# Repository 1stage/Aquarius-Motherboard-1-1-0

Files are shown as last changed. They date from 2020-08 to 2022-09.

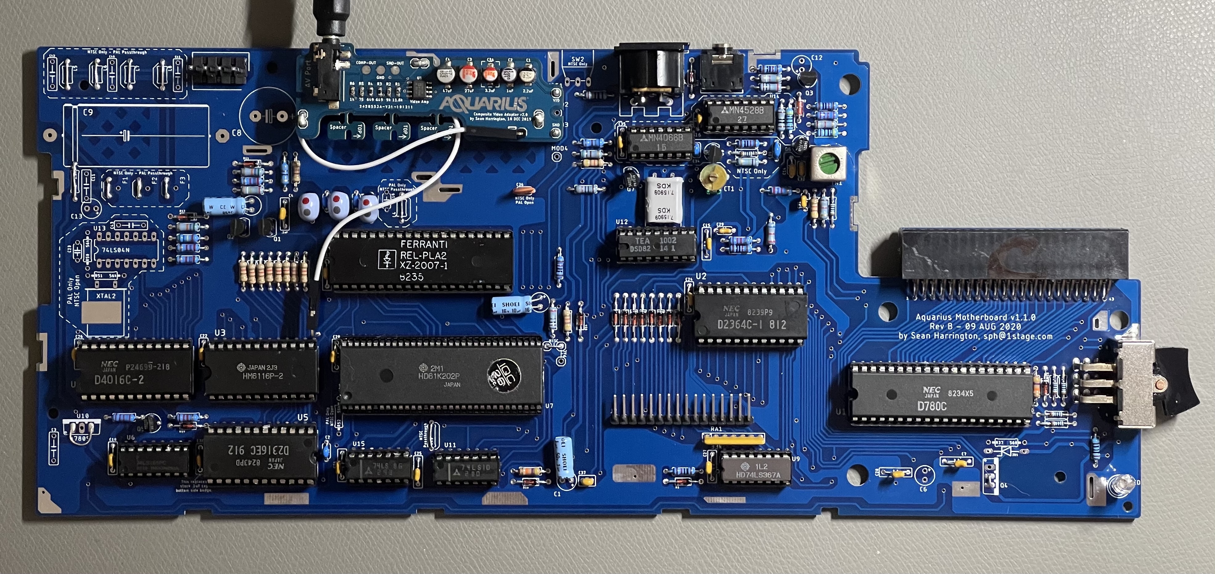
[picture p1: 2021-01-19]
docs/20210119_115113_IMG_6803.JPG

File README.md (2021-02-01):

# Aquarius Motherboard 1-1-0
Aquarius Motherboard 1-1-0 - Rev C

by Sean P. Harrington, sph@1stage.com, http://aquarius.1stage.com, Mack Wharton, aquarius@mack.je, http://aquarius.je
 
## Background
In general, the Aquarius hardware is fairly hardy. Few of the parts go bad, and the system just works, even when stored in harsh or unforgiving environments. Add to that the poor reception the computer had during its brief, 3-4 month sales window in 1983, and there is no REAL reason most people would be interested. But the Mattel Aquarius Computer was the first computer I ever owned. I learned first hand how to program in BASIC, and then how to hack together an audio cable to save those programs to my inexpensive Radio Shack cassette player. However I quickly grew out of it's limited functionality and moved on to a Commodore 64, and then an Apple Macintosh SE, and then Mac II, and then various Windows PCs. It wasn't until Summer of 2019 that I started getting back into retro computers, and it was the pang of guilt I felt in abandoning my first Aquarius that brought me back in.

## Purpose
The purpose of this project is to document and recreate the original Aquarius computer motherboard. This is a like-for-like replacement, and should fit in perfectly in place of the old motherboard. This baseline can be used by other enthusiasts (though we are few and far between) as a starting point for creating new modifications to the system, such as adding a composite video adapter (which I've done) to replace the stock RF modulator, or adding more modern components to "future proof" the system.

Additionally, there was a need to update and correct the "MEKO" schematic from 1986. It was drawn from the PAL board, and values for various components seemed to differ from what was commonly manufactured. From these new schematics, users are welcome to adapt and integrate their own ideas, OR to recreate the system in their eCAD program of choice.

## Caveats
* Some fixes to the stock board were made:
  * The .1uF capacitor that was bodged under U6 has been given a proper set of pads beside U6.
  * Silkscreens were added, with all components being identified. Unfortunately, due to the poor quality of original Radofin documents on the Internet, I had to take a stance and perform a re-number of components, particularly resistors and capacitors. In some cases, these won't match original numbers, but every effort was made to get them as close as possible.
  * Both the PAL-only and NTSC-only components are marked, but only the components for the version being built should be used.
  * As much as possible, original trace paths were recreated (particularly CPU to expansion port), but the traces have been reduced to a 20 mil width on most signals, with all GND and power paths increased to 32 mil width.
  * GND pins now have thermal pads to make soldering and desoldering easier.
* The libraries within the Eagle folder are a mess. I apologize. The board uses a combination of the standard Eagle libraries, some copied/modified versions of those, and some of my own items. I'll eventually try to consolidate them into a single library file. Again, apologies.
* This design was taken from the NTSC version of the Aquarius Motherboard, Radofin part number 5931-4229 A. The values for all components are derived from the NTSC version, and where practical, PAL component values are noted on the schematic. As such, the "part number" embossed on these designs uses 5931-4229 AC to differentiate.
* The schematic does it's best to identify differences between the NTSC and PAL versions, usually with dashed lines surrounding the differences.

## FAQs
* Will these boards be available for sale?
  * https://www.pcbway.com/project/shareproject/Aquarius_Computer_Motherboard_v1_1_0_Rev_C.html
* Can I manufacture and sell the boards myself?
  * Sure, but see the section below on why this is more for SERIOUS hackers than casual users.
* Can you build me a new Aquarius with this PCB?
  * No. I have way too many projects at this time. Also, cost of the components ($$) and my time testing and assembling ($$$) would make this MANY times more expensive than buying a used Aquarius off of eBay.
* Can I build my own, brand new Aquarius computer with this PCB?
  * Realistically, no. There are a handful of custom components (bespoke, we like to say) that ONLY exist in the Aquarius computer... the PLA1 and PLA2, some line filters, and a variable inductor... each of which is impractical to source new/NOS. You will HAVE to cannibalize an old Aquarius to get your new Aquarius to work, so given that, you should PROBABLY just use that old Aquarius instead. They're REMARKABLY robust, and the added time and cost of soldering and testing each component on your new board could just as easily be spent learning about your old computer.
* Okay, so then what's the point of this PCB?
  * For futher development to happen to expand the platform, it was necessary to do the work to document the original Aquarius motherboard. From there, people who are interested in adding new components will have a safer, better-documented source from which to start that development. Examples are an RGB or HDMI video interface, incorporated 32Kb of RAM on the motherboard, USB/SD support, etc.
* I don't use Eagle (too expensive), so will you be making this available in KiCAD or some other open-source/free PCB design tool?
  * No, but with the documentation that exists now, feel free to do so yourself. If everyone agrees that your new files work okay, we'll be happy to add them to this project.
* What's next?
  * See the HW Roadmap (below) for our vision.

## Aquarius Hardware Development Roadmap
(A more up-to-date version of this list is at https://aquarius.1stage.com/aquarius/hw-roadmap)

### Aquarius v1.0.0 : Baseline
* Aquarius v1.1.0 (Rev C): Aquarius 1 stock motherboard, like-for-like replacement, SANCTIONED FREE version. 
  * Aquarius v1.1.0.x : Users can fork at this level for their own purposes, UNSANCTIONED versions.
* Aquarius v1.2.0 : Aquarius 1 modernized motherboard, fits in Aquarius 1 case, unmodified port openings may be used differently, SANCTIONED PAID version.
  * Aquarius v1.2.1 : Integrated composite video ???
  * Aquarius v1.2.2 : Modern power supply ???
  * Aquarius v1.2.3 : Charmap, ROM, updates ???
* Aquarius v1.3.0 : Aquarius 1 motherboard, new layout, new case format, etc. ???
  * Aquarius v1.3.1 : New case design with mechanical keyboard, RGB output, proper serial, etc. ???

### Aquarius v2.0.0 : Baseline (FUTURE)
* Aquarius v2.1.0 : Aquarius 2 stock motherboard, like-for-like replacement, SANCTIONED FREE version.
  * Aquarius v2.1.0.x : Users can fork at this level for their own purposes, UNSANCTIONED versions.
  * Aquarius v2.1.1 : Aquarius 2 motherboard, updated with proper silk screen markings and ground planes, SANCTIONED PAID version.
  * Aquarius v2.1.2 : Aquarius 2 motherboard, updated with bodge fixes, modern component replacements, traces may be updated/optimized, SANCTIONED PAID version.
* Aquarius v2.2.0 : Aquarius 2 modernized motherboard, fits in Aquarius 2 case, unmodified port openings may be used differently, SANCTIONED PAID version.
  * Aquarius v2.2.1 : Charmap, ROM, etc updates ???
* Aquarius v2.3.0 : Aquarius 2 motherboard, new layout, new case format, etc. ???

### Aquarius v3.0.0 : Baseline (FUTURE)
New OPEN computer, modern, programmable system (new video system, RAM system, sound, etc.)
* Aquarius v3.1.0 : Aquarius 3 motherboard, SANCTIONED FREE version

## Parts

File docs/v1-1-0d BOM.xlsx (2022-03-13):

Part | NTSC Value | PAL Value | Device | Package
C1 | 1uF@50 | 10uF@16 | CPOL-USE2.5-6 | E2,5-6
C2 | 10pF | 10pF | C-US050-024X044 | C050-024X044
C3 | .22uF | .22uF | C-US050-025X090 | C050-025X090
C4 | .1uF | .1uF | C-US050-025X090 | C050-025X090
C5 | 2.2uF@50v | 2.2uF@50v | CPOL-USE2.5-6 | E2,5-6
C6 | 47uF@10v | 47uF@10v | CPOL-USE2.5-6 | E2,5-6
C7 | .1uF@25v | .1uF@25v | C-US050-025X090 | C050-025X090
C8 | 1000uF@25v | 1000uF@25v | CPOL-USE7.5-16 | E7,5-16
C9 | 10000uF@16v | 10000uF@16v | CPOL-USE45-18AXIAL | E45-18
C10 | .1uF | .1uF | C-US050-025X090 | C050-025X090
C11 | .1uF | .1uF | C-US050-025X090 | C050-025X090
C12 | 10uF@16v | 10uF@16v | CPOL-USE2.5-6 | E2,5-6
C13 | 10uF@25v | 10uF@25v | CPOL-USE2.5-6 | E2,5-6
C14 | .022uF | .022uF | C-US050-024X044 | C050-024X044
C15 | .1uF | .1uF | C-US050-025X090 | C050-025X090
C16 | open | 82pF | C-US050-024X044 | C050-024X044
C17 | .1uF | .1uF | C-US050-025X090 | C050-025X090
C18 | 82pF | 82pF | C-US050-024X044 | C050-024X044
C19 | 82pF | 82pF | C-US050-024X044 | C050-024X044
C20 | .1uF | .1uF | C-US050-025X090 | C050-025X090
C21 | .1uF | .1uF | C-US050-025X090 | C050-025X090
C22 | .1uF | .1uF | C-US050-025X085 | C050-025X085
C23 | open | 10pF | C-US050-024X044 | C050-024X044
C24 | .1uF | .1uF | C-US050-025X090 | C050-025X090
C25 | .1uF | .1uF | C-US050-025X090 | C050-025X090
C26 | .1uF | .1uF | C-US050-025X085 | C050-025X085
C27 | .1uF | .1uF | C-US050-025X090 | C050-025X090
C28 | .1uF | .1uF | C-US050-025X090 | C050-025X090
C29 | 150pF | 150pF | C-US050-024X044 | C050-024X044
C30 | 10uF@16v | 10uF@16v | CPOL-USE2.5-6 | E2,5-6
C31 | .1uF | .1uF | C-US050-024X044 | C050-024X044
C32 | 100pF | 100pF | C-US025-024X044 | C025-024X044
C33 | 680pF | open | C-US050-024X044 | C050-024X044
C34 | 2pF | open | C-US025-024X044 | C025-024X044
C35 | .1uF | open | C-US050-025X090 | C050-025X090
C36 | .01uF | .01uF | C-US050-024X044 | C050-024X044
C37 | .001uF | open | C-US025-030X050 | C025-030X050
C38 | 100pF | 100pF | C-US050-025X085 | C050-025X085
C39 | 56pF | open | C-US050-024X044 | C050-024X044
C40 | .02uF | .02uF | C-US050-025X090 | C050-025X090
C41 | .02uF | .02uF | C-US050-025X090 | C050-025X090
C42 | .02uF | .02uF | C-US050-025X090 | C050-025X090
C43 | open | 100nF | C-US050-025X090 | C050-025X090
C44 | open | 22pF | C-US050-024X044 | C050-024X044
CT1 | C-TRIMM808 | C-TRIMM808 | CTRIM808-BC | Trimmcapacitor
D1 | 1N4148 | 1N4148 | 1N4148 | DO35-10
D2 | 1N4148H | 1N4148H | 1N4148-12 | DO35-12
D3 | 1N4148H | 1N4148H | 1N4148-12 | DO35-12
D4 | 1N4148H | 1N4148H | 1N4148-12 | DO35-12
D5 | 1N4148H | 1N4148H | 1N4148-12 | DO35-12
D6 | 1N4148H | 1N4148H | 1N4148-12 | DO35-12
D7 | 1N4148H | 1N4148H | 1N4148-12 | DO35-12
D8 | 1N4148H | 1N4148H | 1N4148-12 | DO35-12
D9 | 1N4148H | 1N4148H | 1N4148-12 | DO35-12
D10 | 1N4148 | 1N4148 | 1N4148 | DO35-10
D11 | 1N4148 | 1N4148 | 1N4148 | DO35-10
D12 | 1N4148 | 1N4148 | 1N4148 | DO35-10
D13 | 1N4148 | 1N4148 | 1N4148 | DO35-10
D14 | 1N4148 | 1N4148 | 1N4148 | DO35-10
D15 | 1N4148 | 1N4148 | 1N4148 | DO35-10
D16 | 1N4148 | 1N4148 | 1N4148 | DO35-10
F1 | LCL | LCL | LCL | FILTER
F2 | LCL | LCL | LCL | FILTER
F3 | LCL | LCL | LCL | FILTER
J1 | CR22A-44D-2.54DSA(70)CR22A-44D-2.54DSA(70)CR22A-44D-2.54DSA(70) | CR22A-44D-2.54DSA(70)CR22A-44D-2.54DSA(70)CR22A-44D-2.54DSA(70)
J2 | PINHD-1X17 | PINHD-1X17 | 1X17 | PINHEADER
J3 | 26-60-4040 | 26-60-4040 | 26-60-4040 | SHDR4W155P0X396_1X4_
J4 | AUDIO_JACK_3.5MM_PTH | AUDIO_JACK_3.5MM_PTH | AUDIO_JACK_3.5MM_PTH | AUDIO-JACK
J5 | DIN5 | DIN5 | DIN5 | DIN5-RA-PTH
JP1 | PINHD-1X1 | PINHD-1X1 | 1X01 | PINHEADER
JP2 | PINHD-1X1 | PINHD-1X1 | 1X01 | PINHEADER
JP3 | PINHD-1X1 | PINHD-1X1 | 1X01 | PINHEADER
JP4 | PINHD-1X4 | PINHD-1X4 | 1X04 | PINHEADER
JP5 | PINHD-1X1 | PINHD-1X1 | 1X01 | PINHEADER
JP6 | PINHD-1X1 | PINHD-1X1 | 1X01 | PINHEADER
L-V1 | 10uH@4.43MHz | 10uH@4.43MHz | 10MM-VAR-IND | CL2054-136CB
L1 | L-USTFI0305 | L-USTFI0305 | TFI0305 | INDUCTOR,Americansymbol
L2 | L-USTFI0305 | L-USTFI0305 | TFI0305 | INDUCTOR,Americansymbol
L3 | L-USTFI0305 | L-USTFI0305 | TFI0305 | INDUCTOR,Americansymbol
L4 | L-USTFI0305 | L-USTFI0305 | TFI0305 | INDUCTOR,Americansymbol
L5 | L-USTFI0305 | L-USTFI0305 | TFI0305 | INDUCTOR,Americansymbol
L6 | L-USTFI0305 | L-USTFI0305 | TFI0305 | INDUCTOR,Americansymbol
L7 | L-USTFI0305 | L-USTFI0305 | TFI0305 | INDUCTOR,Americansymbol
L8 | L-USTFI0305 | L-USTFI0305 | TFI0305 | INDUCTOR,Americansymbol
LED1 | LED5MM | LED5MM | LED5MM | LED
MOD1 | PINHD-1X1 | PINHD-1X1 | 1X01 | PINHEADER
MOD2 | PINHD-1X1 | PINHD-1X1 | 1X01 | PINHEADER
MOD3 | PINHD-1X1 | PINHD-1X1 | 1X01 | PINHEADER
MOD4 | PINHD-1X1 | PINHD-1X1 | 1X01 | PINHEADER
Q1 | NPN-TO90 | NPN-TO90 | TO92-E1 | NPNTransistror
Q2 | NPN-TO90 | NPN-TO90 | TO92-E1 | NPNTransistror
Q3 | PNP-TO90 | PNP-TO90 | TO92-E1 | PNPTransistror
Q4 | NPN-TO220V | NPN-TO220V | TO220V | NPNTransistror
Q5 | NPN-TO90 | NPN-TO90 | TO92-E1 | NPNTransistror
Q6 | PNP-TO90 | PNP-TO90 | TO92-E1 | PNPTransistror
Q7 | NPN-TO90 | NPN-TO90 | TO92-E1 | NPNTransistror
Q8 | NPN-TO90 | NPN-TO90 | TO92-E1 | NPNTransistror
R1 | 1k | 1k | R-US_0207/10 | 0207/10
R2 | 1k | 1k | R-US_0207/10 | 0207/10
R3 | 1k | 1k | R-US_0207/10 | 0207/10
R4 | 1k | 1k | R-US_0207/10 | 0207/10
R5 | 10k | 10k | R-US_0207/10 | 0207/10
R6 | 820 | 820 | R-US_0207/10 | 0207/10
R7 | 820 | 820 | R-US_0207/10 | 0207/10
R8 | 820 | 820 | R-US_0207/10 | 0207/10
R9 | 820 | 820 | R-US_0207/10 | 0207/10
R10 | 820 | 820 | R-US_0207/10 | 0207/10
R11 | 820 | 820 | R-US_0207/10 | 0207/10
R12 | 820 | 820 | R-US_0207/10 | 0207/10
R13 | 820 | 820 | R-US_0207/10 | 0207/10
R14 | 2.2k | 680 | R-US_0207/10 | 0207/10
R15 | 1.2k | 2.2k | R-US_0207/10 | 0207/10
R16 | 2.7k | 2.7k | R-US_0207/10 | 0207/10
R17 | 56k | 56k | R-US_0207/10 | 0207/10
R18 | 2.7k | 2.7k | R-US_0207/10 | 0207/10
R19 | 2.7k | 2.7k | R-US_0207/10 | 0207/10
R20 | 390 | 390 | R-US_0207/10 | 0207/10
R21 | 560k | 560k | R-US_0207/10 | 0207/10
R22 | 56k | 56k | R-US_0207/10 | 0207/10
R23 | 100 | 100 | R-US_0207/10 | 0207/10
R24 | 10k | 10k | R-US_0207/10 | 0207/10
R25 | 4.7k | 2.7k | R-US_0207/10 | 0207/10
R26 | 10k | 10k | R-US_0207/10 | 0207/10
R27 | 10k | 10k | R-US_0207/10 | 0207/10
R28 | 2.2k | 2.2k | R-US_0207/10 | 0207/10
R29 | 100 | 100 | R-US_0207/10 | 0207/10
R30 | 10k | 10k | R-US_0207/10 | 0207/10
R31 | 3.9k | 3.9k | R-US_0207/10 | 0207/10
R32 | 820 | 820 | R-US_0207/10 | 0207/10
R33 | 1.2k | 1.2k | R-US_0207/10 | 0207/10
R34 | 6.8k | 6.8k | R-US_0207/10 | 0207/10
R35 | 2.7k | 2.7k | R-US_0207/10 | 0207/10
R36 | 1.8k | 1.8k | R-US_0207/10 | 0207/10
R37 | 560 | 560 | R-US_0207/10 | 0207/10
R38 | 820 | 820 | R-US_0207/10 | 0207/10
R39 | 82 | 82 | R-US_0207/10 | 0207/10
R40 | 180 | 180 | R-US_0207/10 | 0207/10
R41 | 680 | 680 | R-US_0207/10 | 0207/10
R42 | 510 | 510 | R-US_0207/10 | 0207/10
R43 | 4.7k | 4.7k | R-US_0207/10 | 0207/10
R44 | 470 | 470 | R-US_0207/10 | 0207/10
R45 | 47k | 47k | R-US_0207/10 | 0207/10
R46 | 510 | 510 | R-US_0207/10 | 0207/10
R47 | 4.7k | 4.7k | R-US_0207/10 | 0207/10
R48 | 1.8k | 1.8k | R-US_0207/10 | 0207/10
R49 | bridge | 220 | R-US_0207/10 | 0207/10
R50 | open | 1.5k | R-US_0207/10 | 0207/10
R51 | open | 1.5k | R-US_0207/10 | 0207/10
R52 | open | 100 | R-US_0207/10 | 0207/10
R53 | 1k | 1k | R-US_0207/10 | 0207/10
R54 | 1.8k | 1.8k | R-US_0207/10 | 0207/10
R55 | 47k | open | R-US_0207/10 | 0207/10
R56 | 100k | open | R-US_0207/10 | 0207/10
R57 | 1k | open | R-US_0207/10 | 0207/10
R58 | 10k | open | R-US_0207/10 | 0207/10
R59 | 180 | open | R-US_0207/10 | 0207/10
R60 | 470 | open | R-US_0207/10 | 0207/10
RA1 | 33k | 33k | RN06 | RN-7
SW1 | 3PDT-AQ-SWITCH | 3PDT-AQ-SWITCH | 3PDT-AQ-SWITCH | 3PDT-AQ-SWITCH
SW2 | 9077-1 | 9077-1 | 9077-1 | 9077-1
U1 | Z80CPU | Z80CPU | DIL40 | Z80FAMILYDEVICE
U2 | DIL24-6 | DIL24-6 | DIL24-6 | DualInLine
U3 | 6116P | 6116P | DIL24-6 | MEMORY
U4 | 6116P | 6116P | DIL24-6 | MEMORY
U5 | DIL24-6 | DIL24-6 | DIL24-6 | DualInLine
U6 | 74LS165N | 74LS165N | 74LS165N | DIL16
U7 | HD61K202P-PLA1 | HD61K202P-PLA1 | HD61K202P-PLA1 | HD61K202P-PLA1
U8 | DIL40 | DIL40 | DIL40 | DualInLine
U9 | 74367N | 74367N | 74367N | DIL16
U10 | 7805 | 7805 | 7805TV | TO220V
U11 | 74LS10N | 74LS10N | 74LS10N | DIL14
U12 | DIL18 | DIL18 | DIL18 | DualInLine/Socket
U13 | 74LS04N | 74LS04N | 74LS04N | DIL14
U14 | 4528N | 4528N | 4528N | DIL16
U15 | 74LS86N | 74LS86N | 74LS86N | DIL14
U16 | 744066N | 744066N | 744066N | DIL14
XTAL1 | 7.15909MhZ | 8.867239MhZ | Q | CRYSTAL
XTAL2 | open | 7.15909Mhz | Q | CRYSTAL
ZD1 | ZENER-DIODEZD-10 | ZENER-DIODEZD-10 | ZDIO-10 | Z-Diode
ZD2 | ZENER-DIODEZD-7.5 | ZENER-DIODEZD-7.5 | ZDIO-7.5 | Z-Diode

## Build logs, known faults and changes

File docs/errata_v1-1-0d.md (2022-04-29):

# Errata - Rev D Boards
Updated 30 APR 2022, by Sean Harrington<br/>

## Abstract
Erratas to Rev D board.

## New
* None

## Feedback Needed
* None

## Resolved
* Fixed missing pad on BACK upper power switch mount.
* Added back pads between lower switch contacts.
* Added auxiliary power connector (+5v & GND) above PLA2 for Comp/HDMI solutions.

## Delayed / Out of Scope
* ROM & CHROM 24 to 28 pin change - Deferred. It's impractical to add on-board support for both 24 pin (stock) and 28 pin (modern replacement) headers. 19 JAN 2021, SPH.

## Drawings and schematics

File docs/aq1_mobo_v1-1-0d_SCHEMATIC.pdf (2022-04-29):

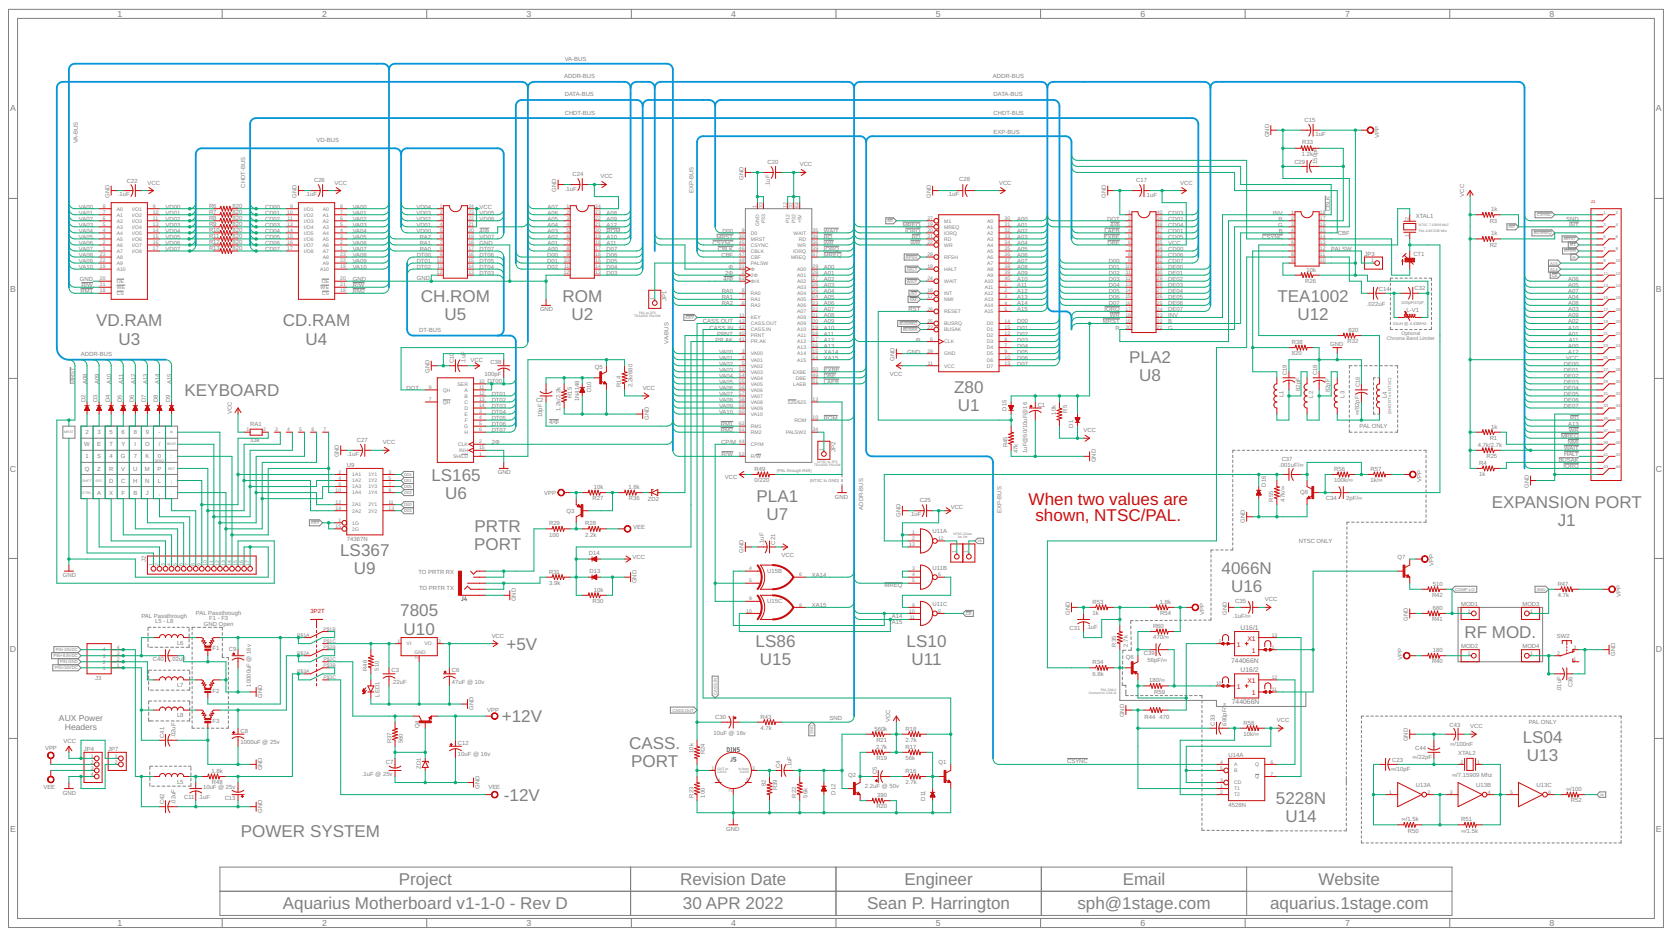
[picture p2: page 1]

Optional Chroma Band Limiter

(NTSC to GND) NTSC to JP3 TEA1002 PALSW

EXP-BUS
When two values are
shown, NTSC/PAL.

GND Open PAL Passthrough

PAL ONLY Connect to U16-11

CASS OUT to CASS

Project | Revision Date | Engineer | Email | Website

Aquarius Motherboard v1-1-0 - Rev D | 30 APR 2022 | Sean P. Harrington | sph@1stage.com | aquarius.1stage.com

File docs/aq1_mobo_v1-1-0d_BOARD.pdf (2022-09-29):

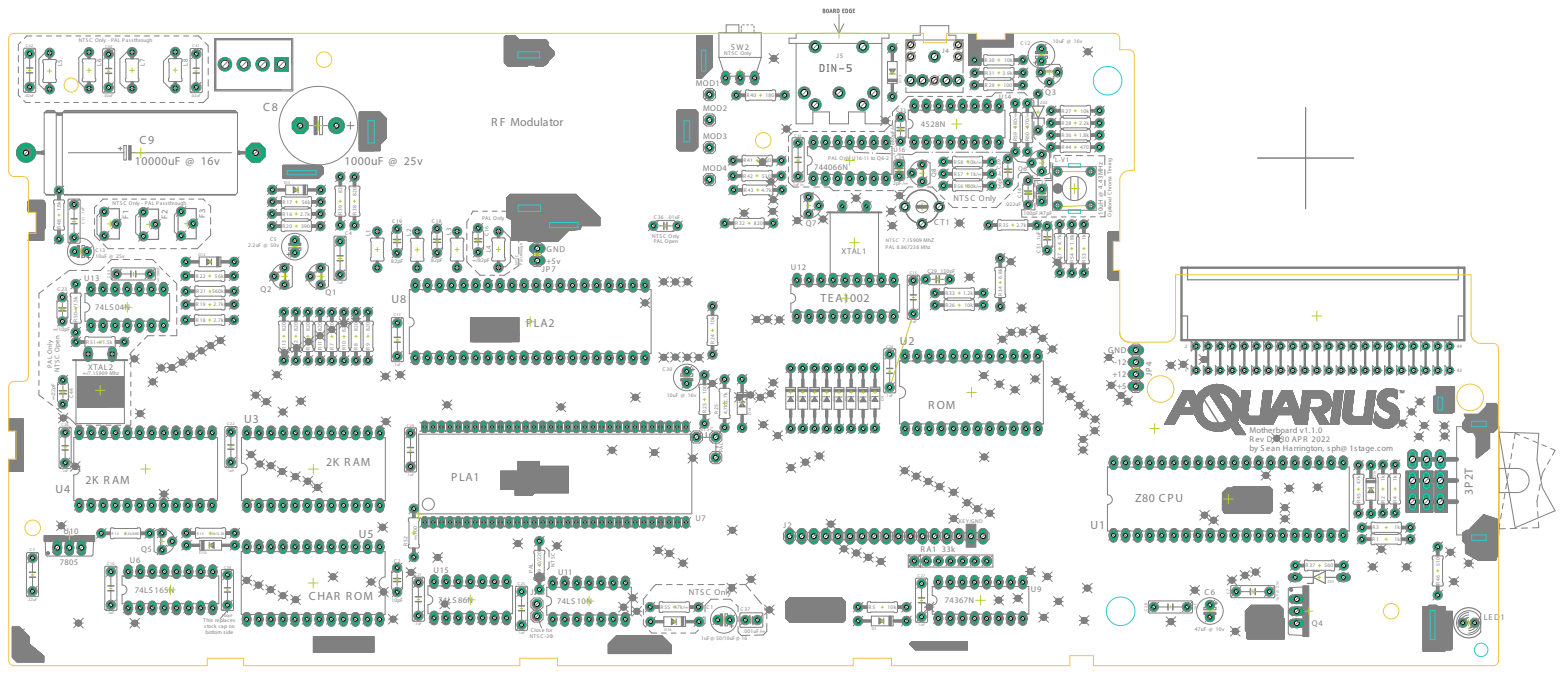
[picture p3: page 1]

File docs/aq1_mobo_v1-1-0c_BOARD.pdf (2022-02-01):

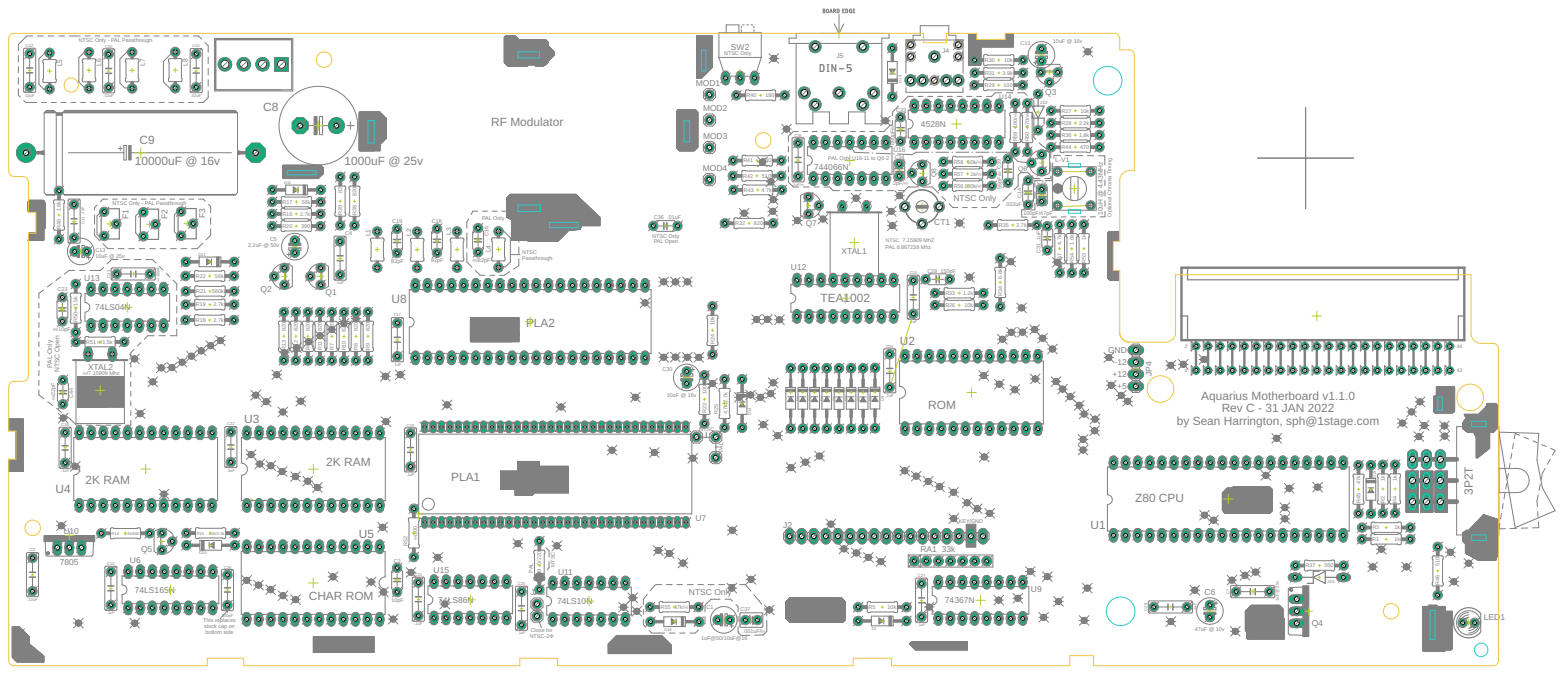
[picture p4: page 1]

NTSC Only - PAL Passthrough

PAL Only NTSC Only - PAL Passthrough

NTSC Only PAL Open

PAL Only NTSC Open

by Sean Harrington, sph@1stage.com

PAL Close for NTSC-2Φ

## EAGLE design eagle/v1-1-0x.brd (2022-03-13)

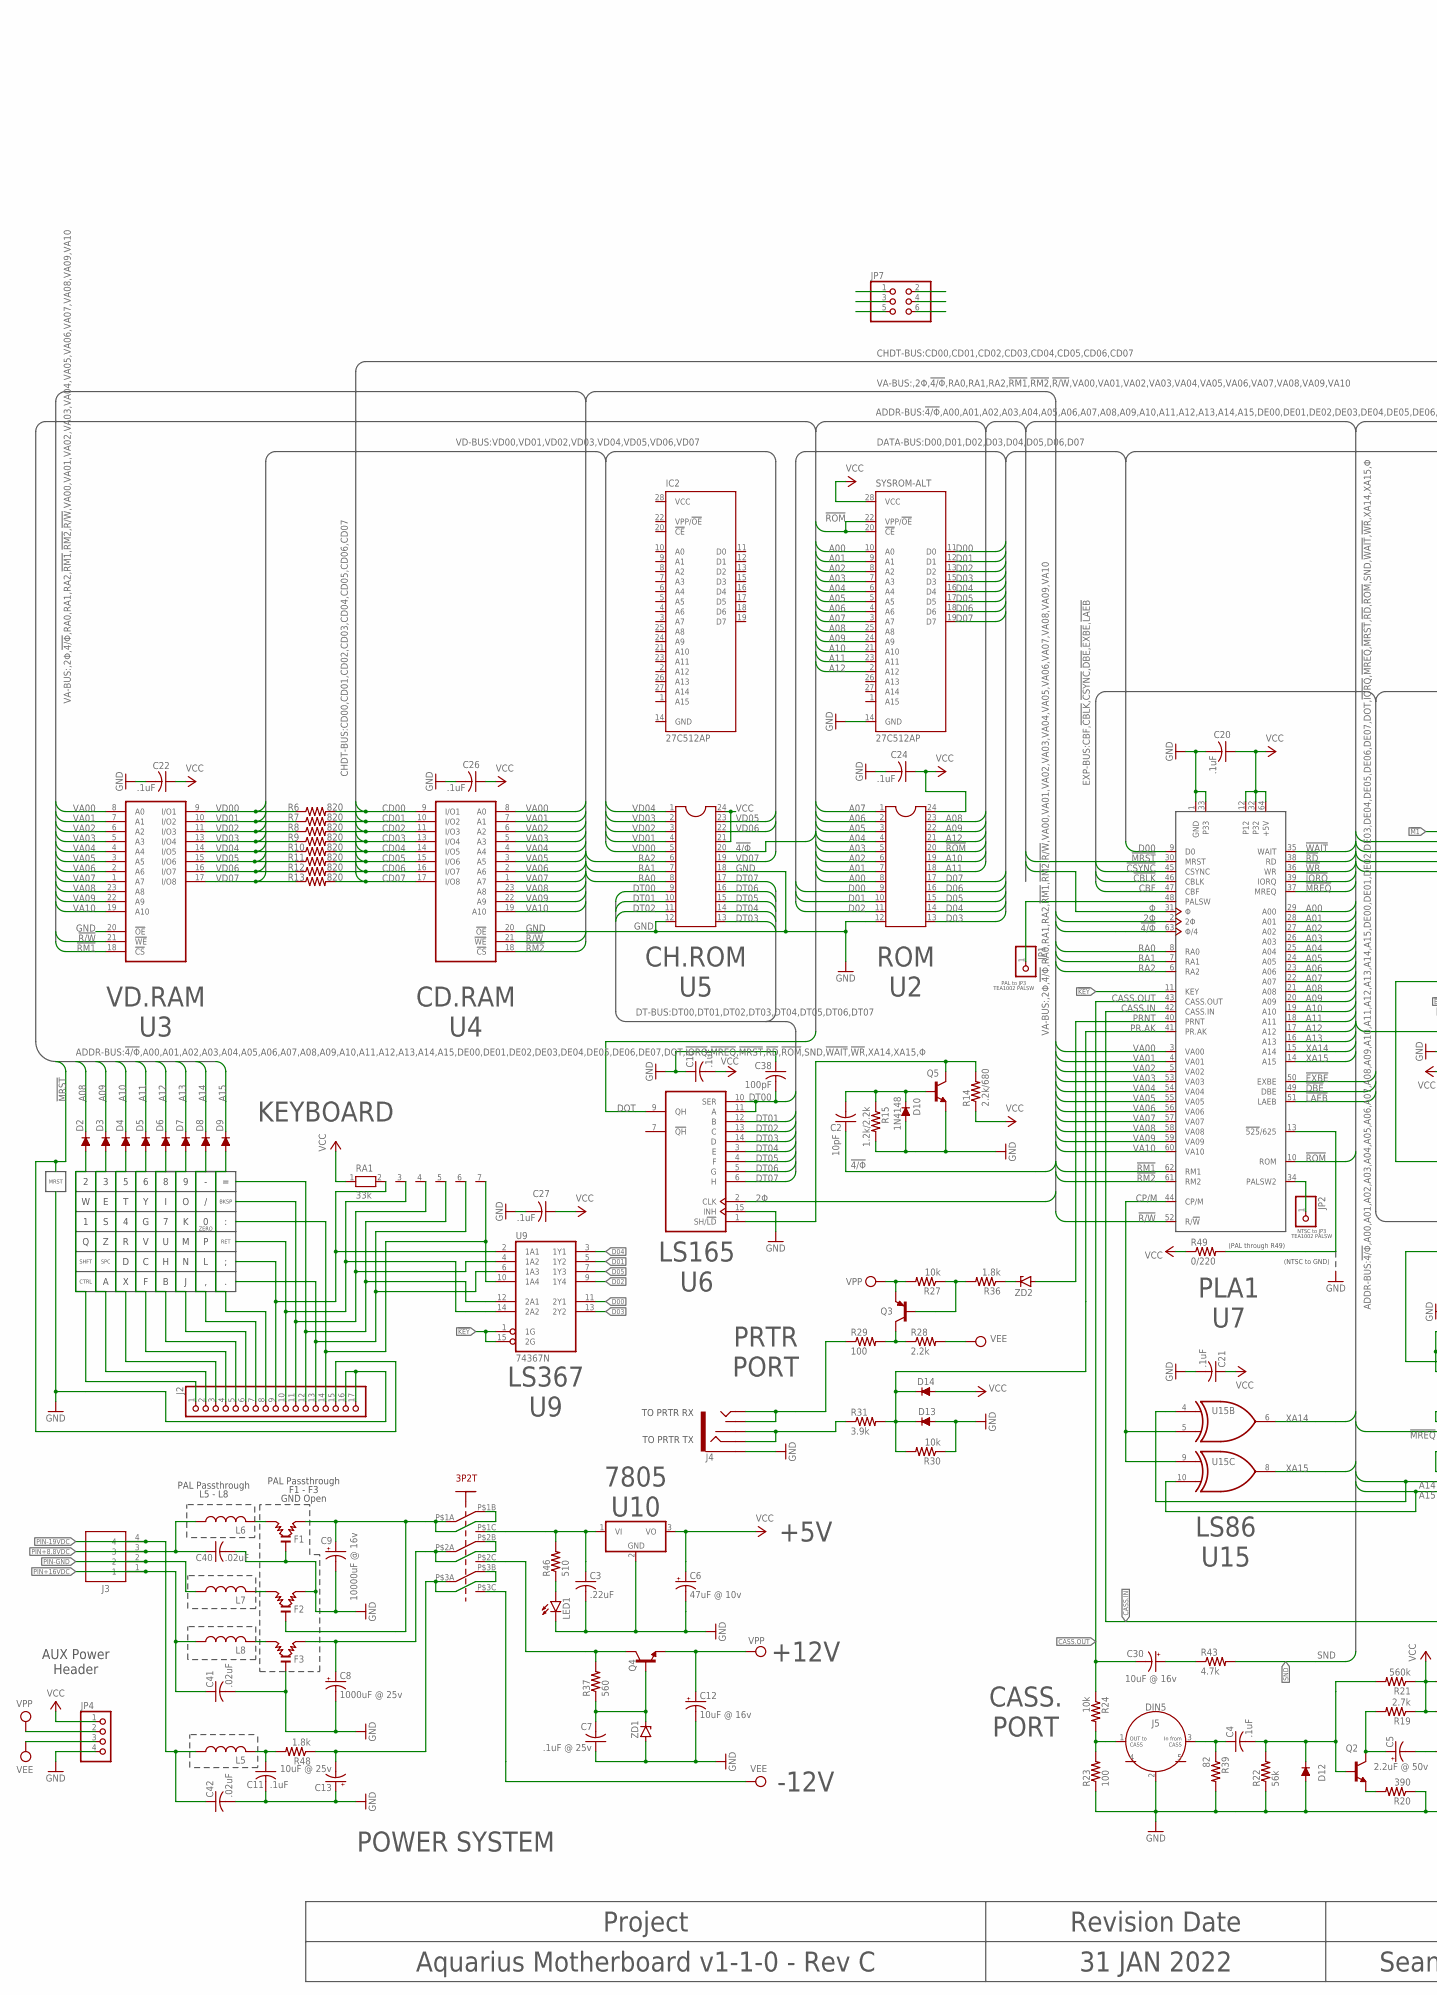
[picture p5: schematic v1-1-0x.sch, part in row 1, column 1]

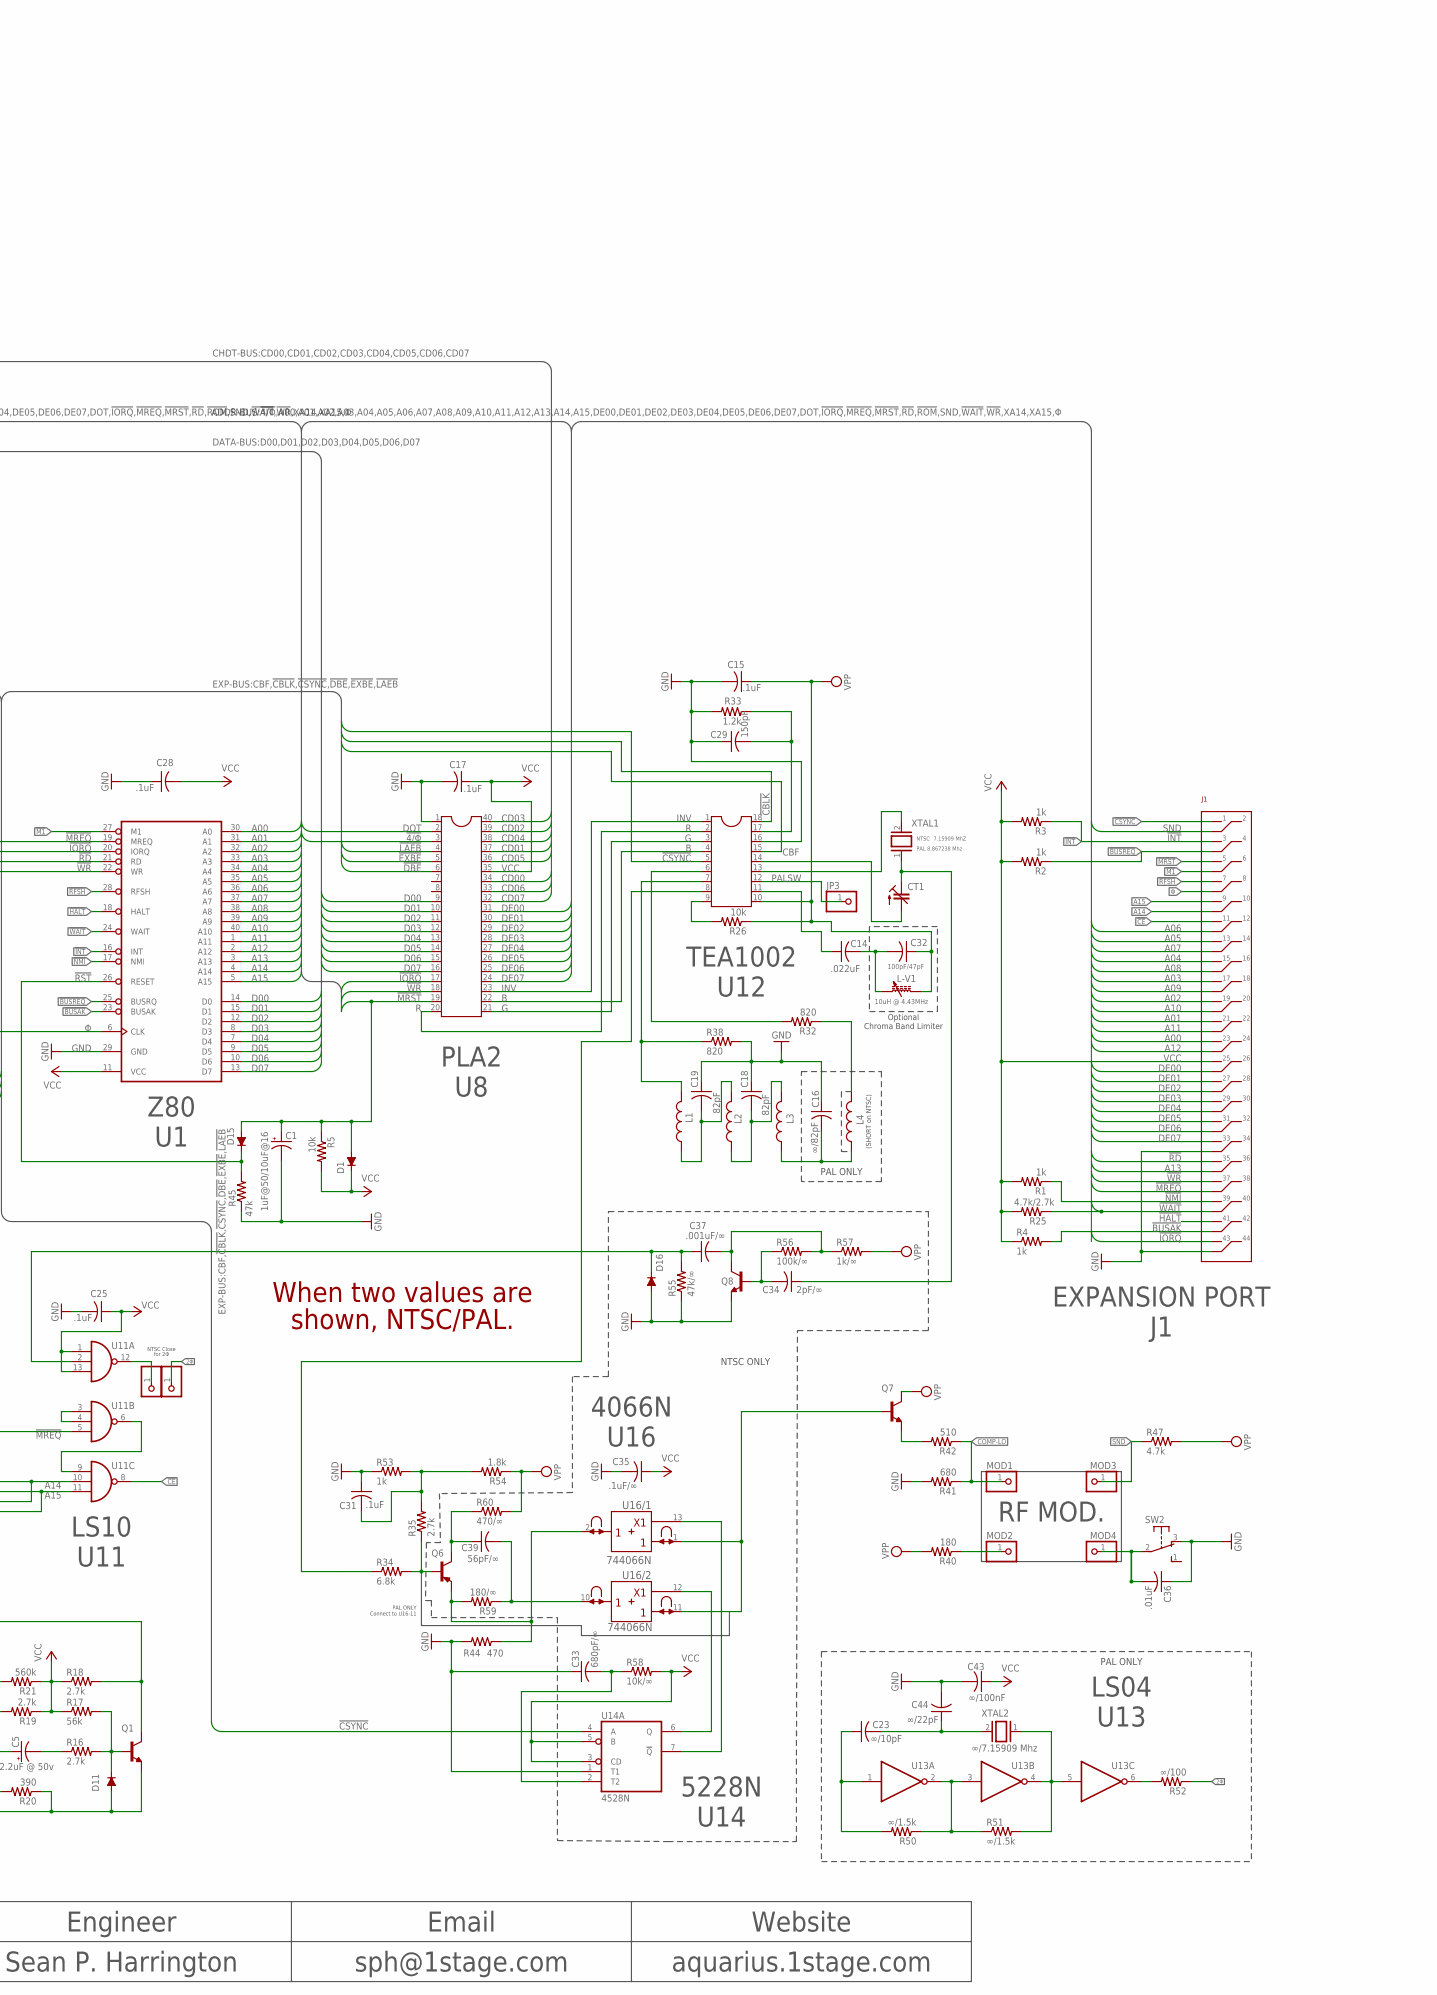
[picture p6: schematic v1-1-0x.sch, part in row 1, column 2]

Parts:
C1: 1uF@50/10uF@16; E2,5-6
C2: 10pF; C050-024X044
C3: .22uF; C050-025X090
C4, C10, C11, C15, C17, C20, C21, C24, C25, C27, C28: .1uF; C050-025X090
C5: 2.2uF @ 50v; E2,5-6
C6: 47uF @ 10v; E2,5-6
C7: .1uF @ 25v; C050-025X090
C8: 1000uF @ 25v; E7,5-16
C9: 10000uF @ 16v; E45-18
C12, C30: 10uF @ 16v; E2,5-6
C13: 10uF @ 25v; E2,5-6
C14: .022uF; C050-024X044
C16: ∞/82pF; C050-024X044
C18, C19: 82pF; C050-024X044
C22, C26: .1uF; C050-025X085
C23: ∞/10pF; C050-024X044
C29: 150pF; C050-024X044
C31: .1uF; C050-024X044
C32: 100pF/47pF; C025-024X044
C33: 680pF/∞; C050-024X044
C34: 2pF/∞; C025-024X044
C35: .1uF/∞; C050-025X090
C36: .01uF; C050-024X044
C37: .001uF/∞; C025-030X050
C38: 100pF; C050-025X085
C39: 56pF/∞; C050-024X044
C40, C41, C42: .02uF; C050-025X090
C43: ∞/100nF; C050-025X090
C44: ∞/22pF; C050-024X044
CT1: C-TRIMM808; CTRIM808-BC
D1, D10, D11, D12, D13, D14, D15, D16: 1N4148; DO35-10
D2, D3, D4, D5, D6, D7, D8, D9: 1N4148H; DO35-12
F1, F2, F3: LCL
IC2: 27C512AP; DIL28-6
J1: CR22A-44D-2.54DSA(70)
J2: PINHD-1X17; 1X17
J3: 26-60-4040; SHDR4W155P0X396_1X4_1570X1001X
J4: AUDIO_JACK_3.5MM_PTH; AUDIO-JACK
J5: DIN5; DIN5-RA-PTH
JP1, JP2, JP3, JP5, JP6: PINHD-1X1; 1X01
JP4: PINHD-1X4; 1X04
JP7: PINHD-2X3; 2X03
L1, L2, L3, L4, L5, L6, L7, L8: L-USTFI0305; TFI0305
L-V1: 10uH @ 4.43MHz; 10MM-VAR-IND
LED1: LED5MM
MOD1, MOD2, MOD3, MOD4: PINHD-1X1; 1X01
Q1, Q2, Q5, Q7, Q8: -NPN-TO92-E1; TO92-E1
Q3, Q6: -PNP-TO92-E1; TO92-E1
Q4: -NPN-TO220V; TO220V
R1, R2, R3, R4, R53: 1k; 0207/10
R5, R24, R26, R27, R30: 10k; 0207/10
R6, R7, R8, R9, R10, R11, R12, R13, R32, R38: 820; 0207/10
R14: 2.2k/680; 0207/10
R15: 1.2k/2.2k; 0207/10
R16, R18, R19, R35: 2.7k; 0207/10
R17, R22: 56k; 0207/10
R20: 390; 0207/10
R21: 560k; 0207/10
R23, R29: 100; 0207/10
R25: 4.7k/2.7k; 0207/10
R28: 2.2k; 0207/10
R31: 3.9k; 0207/10
R33: 1.2k; 0207/10
R34: 6.8k; 0207/10
R36, R48, R54: 1.8k; 0207/10
R37: 560; 0207/10
R39: 82; 0207/10
R40: 180; 0207/10
R41: 680; 0207/10
R42, R46: 510; 0207/10
R43, R47: 4.7k; 0207/10
R44: 470; 0207/10
R45: 47k; 0207/10
R49: 0/220; 0207/10
R50, R51: ∞/1.5k; 0207/10
R52: ∞/100; 0207/10
R55: 47k/∞; 0207/10
R56: 100k/∞; 0207/10
R57: 1k/∞; 0207/10
R58: 10k/∞; 0207/10
R59: 180/∞; 0207/10
R60: 470/∞; 0207/10
RA1: 33k; RN-7
SW1: 3PDT-AQ-SWITCH
SW2: 9077-1
SYSROM-ALT: 27C512AP; DIL28-6
U1: Z80CPU; DIL40
U2, U5: DIL24-6
U3, U4: 6116P; DIL24-6
U6: 74LS165N; DIL16
U7: HD61K202P-PLA1
U8: DIL40
U9: 74367N; DIL16
U10: 7805; TO220V
U11: 74LS10N; DIL14
U12: DIL18
U13: 74LS04N; DIL14
U14: 4528N; DIL16
U15: 74LS86N; DIL14
U16: 744066N; DIL14
XTAL1: 7.15909 MhZ; Q
XTAL2: ∞/7.15909 Mhz; Q
ZD1: ZENER-DIODEZD-10; ZDIO-10
ZD2: ZENER-DIODEZD-7.5; ZDIO-7.5

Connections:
2Φ: JP6.1, R52.1, U6.2 (CLK), U7.2 (2Φ)
2Φ-NTSC: JP5.1, U11.12 (O)
!4/Φ: C2.1, U5.20, U7.63 (Φ/4), U8.3
!BUSAK: J1.P$42 (X42), R4.2, U1.23 (BUSAK)
!BUSREQ: J1.P$4 (X4), R2.1, U1.25 (BUSRQ)
!CBLK: U7.46 (CBLK), U12.18
!CE: J1.P$11 (X11), U11.8 (O)
!CSYNC: J1.P$1 (X1), U7.45 (CSYNC), U12.5, U14.4 (A)
!DBE: U7.49 (DBE), U8.6
!EXBE: U7.50 (EXBE), U8.5
!HALT: J1.P$41 (X41), U1.18 (HALT)
!INT: J1.P$3 (X3), R3.1, U1.16 (INT)
!IORQ: J1.P$43 (X43), U1.20 (IORQ), U7.39 (IORQ), U8.17
!KEY: U7.11 (KEY), U9.1 (1G), U9.15 (2G)
!LAEB: U7.51 (LAEB), U8.4
!M1: J1.P$6 (X6), U1.27 (M1)
!MREQ: J1.P$38 (X38), U1.19 (MREQ), U7.37 (MREQ), U11.5 (I2)
!MRST: C1.+, D1.A, D15.A, J1.P$5 (X5), J2.15, R5.1, U7.30 (MRST), U8.19
!NMI: J1.P$39 (X39), R1.1, U1.17 (NMI)
!PL: Q5.1 (C), R14.2, U6.1 (SH/!LD)
!R/W: U3.21 (!WE), U4.21 (!WE), U7.52 (R/!W)
!RD: J1.P$35 (X35), U1.21 (RD), U7.38 (RD)
!RFSH: J1.P$7 (X7), U1.28 (RFSH)
!RM1: U3.18 (!CS), U7.62 (RM1)
!RM2: U4.18 (!CS), U7.61 (RM2)
!ROM: SYSROM-ALT.20 (!CE), SYSROM-ALT.22 (VPP/!OE), U2.20, U7.10 (ROM)
!RST: D15.C, R45.2, U1.26 (RESET)
!WAIT: J1.P$40 (X40), R25.1, U1.24 (WAIT), U7.35 (WAIT)
!WR: J1.P$37 (X37), U1.22 (WR), U7.36 (WR), U8.18
A00: J1.P$23 (X23), SYSROM-ALT.10 (A0), U1.30 (A0), U2.8, U7.29 (A00)
A01: J1.P$21 (X21), SYSROM-ALT.9 (A1), U1.31 (A1), U2.7, U7.28 (A01)
A02: J1.P$19 (X19), SYSROM-ALT.8 (A2), U1.32 (A2), U2.6, U7.27 (A02)
A03: J1.P$17 (X17), SYSROM-ALT.7 (A3), U1.33 (A3), U2.5, U7.26 (A03)
A04: J1.P$15 (X15), SYSROM-ALT.6 (A4), U1.34 (A4), U2.4, U7.25 (A04)
A05: J1.P$13 (X13), SYSROM-ALT.5 (A5), U1.35 (A5), U2.3, U7.24 (A05)
A06: J1.P$12 (X12), SYSROM-ALT.4 (A6), U1.36 (A6), U2.2, U7.23 (A06)
A07: J1.P$14 (X14), SYSROM-ALT.3 (A7), U1.37 (A7), U2.1, U7.22 (A07)
A08: D2.C, J1.P$16 (X16), SYSROM-ALT.25 (A8), U1.38 (A8), U2.23, U7.21 (A08)
A09: D3.C, J1.P$18 (X18), SYSROM-ALT.24 (A9), U1.39 (A9), U2.22, U7.20 (A09)
A10: D4.C, J1.P$20 (X20), SYSROM-ALT.21 (A10), U1.40 (A10), U2.19, U7.19 (A10)
A11: D5.C, J1.P$22 (X22), SYSROM-ALT.23 (A11), U1.1 (A11), U2.18, U7.18 (A11)
A12: D6.C, J1.P$24 (X24), SYSROM-ALT.2 (A12), U1.2 (A12), U2.21, U7.17 (A12)
A13: D7.C, J1.P$36 (X36), U1.3 (A13), U7.16 (A13)
A14: D8.C, J1.P$10 (X10), U1.4 (A14), U11.10 (I1), U15.4 (I0)
A15: D9.C, J1.P$9 (X9), U1.5 (A15), U11.11 (I2), U15.10 (I1)
B: U8.22, U12.4
CASS.IN: Q1.1 (C), R18.2, U7.42 (CASS.IN)
CASS.OUT: C30.-, R24.1, U7.43 (CASS.OUT)
CBF: U7.47 (CBF), U12.15
CD00: R6.2, U4.9 (I/O1), U8.34
CD01: R7.2, U4.10 (I/O2), U8.37
CD02: R8.2, U4.11 (I/O3), U8.39
CD03: R9.2, U4.13 (I/O4), U8.40
CD04: R10.2, U4.14 (I/O5), U8.38
CD05: R11.2, U4.15 (I/O6), U8.36
CD06: R12.2, U4.16 (I/O7), U8.33
CD07: R13.2, U4.17 (I/O8), U8.32
COMP-LO: MOD1.1, R41.1, R42.1
CP/M: U7.44 (CP/M), U15.5 (I1), U15.9 (I0)
D00: SYSROM-ALT.11 (D0), U1.14 (D0), U2.9, U7.9 (D0), U8.9, U9.11 (2Y1)
D01: SYSROM-ALT.12 (D1), U1.15 (D1), U2.10, U8.10, U9.5 (1Y2)
D02: SYSROM-ALT.13 (D2), U1.12 (D2), U2.11, U8.11, U9.9 (1Y4)
D03: SYSROM-ALT.15 (D3), U1.8 (D3), U2.13, U8.12, U9.13 (2Y2)
D04: SYSROM-ALT.16 (D4), U1.7 (D4), U2.14, U8.13, U9.3 (1Y1)
D05: SYSROM-ALT.17 (D5), U1.9 (D5), U2.15, U8.14, U9.7 (1Y3)
D06: SYSROM-ALT.18 (D6), U1.10 (D6), U2.16, U8.15
D07: SYSROM-ALT.19 (D7), U1.13 (D7), U2.17, U8.16
DE00: J1.P$26 (X26), U8.31
DE01: J1.P$27 (X27), U8.30
DE02: J1.P$28 (X28), U8.29
DE03: J1.P$29 (X29), U8.28
DE04: J1.P$30 (X30), U8.27
DE05: J1.P$31 (X31), U8.26
DE06: J1.P$32 (X32), U8.25
DE07: J1.P$33 (X33), U8.24
DOT: U6.9 (QH), U8.2
DT00: C38.2, U5.9, U6.10 (SER), U6.11 (A)
DT01: U5.10, U6.12 (B)
DT02: U5.11, U6.13 (C)
DT03: U5.13, U6.14 (D)
DT04: U5.14, U6.3 (E)
DT05: U5.15, U6.4 (F)
DT06: U5.16, U6.5 (G)
DT07: U5.17, U6.6 (H)
G: U8.21, U12.3
GND: C1.-, C3.2, C6.-, C7.1, C8.-, C9.-, C10.1, C11.2, C12.-, C13.+, C15.2, C16.1, C17.2, C18.1, C19.1, C20.2, C21.2, C22.2, C24.2, C25.2, C26.2, C27.2, C28.1, C29.1, C31.1, C33.1, C35.2, C36.1, C38.1, C40.2, C41.2, C42.2, C43.2, C44.2, D10.A, D11.A, D12.A, D13.A, D16.A, F1.0 (GND), F2.2, F3.0 (GND), IC2.14 (GND), J1.P$34 (X34), J1.P$44 (X44), J2.16, J2.17, J4.SLEEVE, J5.2, JP4.4, LED1.K (C), Q1.3 (E), Q5.3 (E), Q8.3 (E), R15.2, R20.1, R22.1, R23.1, R30.1, R33.2, R38.2, R39.2, R41.2, R44.2, R45.1, R53.1, R55.1, SW2.3 (O), SYSROM-ALT.14 (GND), U1.29 (GND), U2.12, U3.12 (GND), U3.20 (!OE), U4.12 (GND), U4.20 (!OE), U5.12, U5.18, U6.8 (GND), U6.15 (INH), U7.1 (GND), U7.33, U8.1, U9.8 (GND), U10.2 (GND), U11.7 (GND), U12.16, U13.7 (GND), U14.1 (T1), U14.8 (VSS), U15.7 (GND), U16.7 (-UB), ZD1.A
INV: U8.23, U12.1
KH01: D2.A, J2.1
KH02: D3.A, J2.2
KH03: D4.A, J2.3
KH04: D5.A, J2.4
KH05: D6.A, J2.5
KH06: D7.A, J2.6
KH07: D8.A, J2.7
KH08: D9.A, J2.8
KH09: J2.9, RA1.2, U9.2 (1A1)
KH10: J2.10, RA1.3, U9.14 (2A2)
KH11: J2.11, RA1.4, U9.4 (1A2)
KH12: J2.12, RA1.5, U9.12 (2A1)
KH13: J2.13, RA1.6, U9.6 (1A3)
KH14: J2.14, RA1.7, U9.10 (1A4)
unnamed: R49.2, U7.13 (!525!/625)
unnamed: U11.3 (I0), U11.4 (I1)
unnamed: JP2.1, U7.34 (PALSW2)
unnamed: U11.6 (O), U11.9 (I0)
unnamed: C29.2, R33.1, U12.17
unnamed: C5.+, Q2.1 (C), R19.2
unnamed: C4.2, D12.C, Q2.2 (B), R21.2, R22.2
unnamed: Q2.3 (E), R20.2
unnamed: C9.+, F1.2, F2.0 (GND), SW1.P$1A, SW1.P$1B
unnamed: C13.-, R48.1, SW1.P$3A, SW1.P$3B
unnamed: J4.TIP, J4.TSH, R29.1
unnamed: Q6.2 (B), R34.2, R35.1
unnamed: C3.1, R46.2, SW1.P$1C, U10.1 (VI)
unnamed: Q4.2 (C), R37.2, SW1.P$2C
unnamed: C16.2, L3.1, L4.1
unnamed: C19.2, L1.1, L2.2
unnamed: C2.2, D10.C, Q5.2 (B), R15.1
unnamed: F3.1, L8.2
unnamed: R26.2, U12.9
unnamed: C31.2, R35.2, R53.2, R54.2
unnamed: C18.2, L2.1, L3.2
unnamed: Q3.1 (C), R28.1, R29.2
unnamed: L4.2, R32.1
unnamed: C34.1, CT1.1 (E), XTAL1.1
unnamed: CT1.2 (A), U12.14
unnamed: R32.2, U12.6
unnamed: L1.2, R38.1, U12.7
unnamed: U12.13, XTAL1.2
unnamed: U14.6 (Q), U16.12 (C)
unnamed: J5.1, R23.2, R24.2
unnamed: Q7.3 (E), R42.2
unnamed: C30.+, R43.1
unnamed: C14.1, U12.11
unnamed: Q3.2 (B), R27.1, R36.2
unnamed: R34.1, U12.8
unnamed: C36.2, MOD4.1, SW2.2
unnamed: C4.1, J5.3, R39.1
unnamed: C37.1, D16.C, R55.2, U11.2 (I1)
unnamed: Q6.3 (E), R44.1, R59.2, U16.2 (B)
unnamed: JP1.1, U7.48 (PALSW)
unnamed: C33.2, R58.1, U14.2 (T2)
unnamed: C37.2, Q8.1 (C), R56.2, R57.1
unnamed: Q7.2 (B), U16.1 (A), U16.11 (A)
unnamed: LED1.A, R46.1
unnamed: R52.2, U13.6 (O)
unnamed: C7.2, Q4.1 (B), R37.1, ZD1.C
unnamed: D11.C, Q1.2 (B), R16.2, R17.2
unnamed: R36.1, ZD2.C
unnamed: C39.1, Q6.1 (C), R60.1
unnamed: J4.RING, J4.RSH, R31.1
unnamed: U14.7 (!Q), U16.13 (C)
unnamed: R50.1, R51.1, U13.2 (O), U13.3 (I)
unnamed: C23.1, R50.2, U13.1 (I)
unnamed: C39.2, R59.1, U16.10 (B)
unnamed: R51.2, U13.4 (O), U13.5 (I), XTAL2.1
unnamed: C23.2, C44.1, XTAL2.2
unnamed: F2.1, L7.2
unnamed: C34.2, Q8.2 (B), R56.1
unnamed: C8.+, F3.2, SW1.P$2A, SW1.P$2B
unnamed: F1.1, L6.2
unnamed: C11.1, L5.2, R48.2
unnamed: MOD2.1, R40.1
unnamed: C14.2, C32.2, L-V1.P$1, L-V1.P$3
unnamed: C5.-, R16.1
PALSW: JP3.1, U12.12
PIN+8.8VDC: C40.1, J3.3, L6.1
PIN+16VDC: C41.1, J3.1, L8.1
PIN-19VDC: C42.1, J3.4, L5.1
PIN-GND: J3.2, L7.1
PR.AK: D13.C, D14.C, R30.2, R31.2, U7.41 (PR.AK)
PRNT: U7.40 (PRNT), ZD2.A
R: U8.20, U12.2
RA0: U5.8, U7.8 (RA0)
RA1: U5.7, U7.7 (RA1)
RA2: U5.6, U7.6 (RA2)
SND: J1.P$2 (X2), MOD3.1, R43.2, R47.1
VA00: U3.8 (A0), U4.8 (A0), U7.3 (VA00)
VA01: U3.7 (A1), U4.7 (A1), U7.4 (VA01)
VA02: U3.6 (A2), U4.6 (A2), U7.5 (VA02)
VA03: U3.5 (A3), U4.5 (A3), U7.53 (VA03)
VA04: U3.4 (A4), U4.4 (A4), U7.54 (VA04)
VA05: U3.3 (A5), U4.3 (A5), U7.55 (VA05)
VA06: U3.2 (A6), U4.2 (A6), U7.56 (VA06)
VA07: U3.1 (A7), U4.1 (A7), U7.57 (VA07)
VA08: U3.23 (A8), U4.23 (A8), U7.58 (VA08)
VA09: U3.22 (A9), U4.22 (A9), U7.59 (VA09)
VA10: U3.19 (A10), U4.19 (A10), U7.60 (VA10)
VCC: C6.+, C10.2, C17.1, C20.1, C21.1, C22.1, C24.1, C25.1, C26.1, C27.1, C28.2, C35.1, C43.1, D1.C, D14.A, IC2.28 (VCC), J1.P$25 (X25), JP4.1, R1.2, R2.2, R3.2, R4.1, R5.2, R14.1, R17.1, R18.1, R19.1, R21.1, R25.2, R49.1, R58.2, RA1.1, SYSROM-ALT.28 (VCC), U1.11 (VCC), U2.24, U3.24 (VCC), U4.24 (VCC), U5.21, U5.24, U6.16 (VCC), U7.12, U7.32, U7.64 (+5V), U8.35, U9.16 (VCC), U10.3 (VO), U11.1 (I0), U11.13 (I2), U11.14 (VCC), U13.14 (VCC), U14.3 (CD), U14.5 (B), U14.16 (VDD), U15.14 (VCC), U16.14 (+UB)
VD00: R6.1, U3.9 (I/O1), U5.5
VD01: R7.1, U3.10 (I/O2), U5.4
VD02: R8.1, U3.11 (I/O3), U5.3
VD03: R9.1, U3.13 (I/O4), U5.2
VD04: R10.1, U3.14 (I/O5), U5.1
VD05: R11.1, U3.15 (I/O6), U5.23
VD06: R12.1, U3.16 (I/O7), U5.22
VD07: R13.1, U3.17 (I/O8), U5.19
VEE: JP4.3, R28.2, SW1.P$3C
VPP: C12.+, C15.1, C32.1, JP4.2, L-V1.P$2, L-V1.P$4, Q3.3 (E), Q4.3 (E), Q7.1 (C), R26.1, R27.2, R40.2, R47.2, R54.1, R57.2, R60.2, U12.10
XA14: U7.15 (A14), U15.6 (O)
XA15: U7.14 (A15), U15.8 (O)
Φ: J1.P$8 (X8), U1.6 (CLK), U7.31 (Φ)

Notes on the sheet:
Z80 U1
PLA1 U7
PLA2 U8
TEA1002 U12
EXPANSION PORT J1
ROM U2
CH.ROM U5
CD.RAM U4
VD.RAM U3
LS165 U6
LS367 U9
SHFT
CTRL
BKSP
SPC
RET
ZERO
MRST
KEYBOARD
POWER SYSTEM
RF MOD.
PAL ONLY
(SHORT on NTSC)
7805 U10
PRTR PORT
CASS. PORT
LS86 U15
LS10 U11
Sean P. Harrington
Engineer
sph@1stage.com
Email
Aquarius Motherboard v1-1-0 - Rev C
Project
31 JAN 2022
Revision Date
Website
aquarius.1stage.com
5228N U14
4066N U16

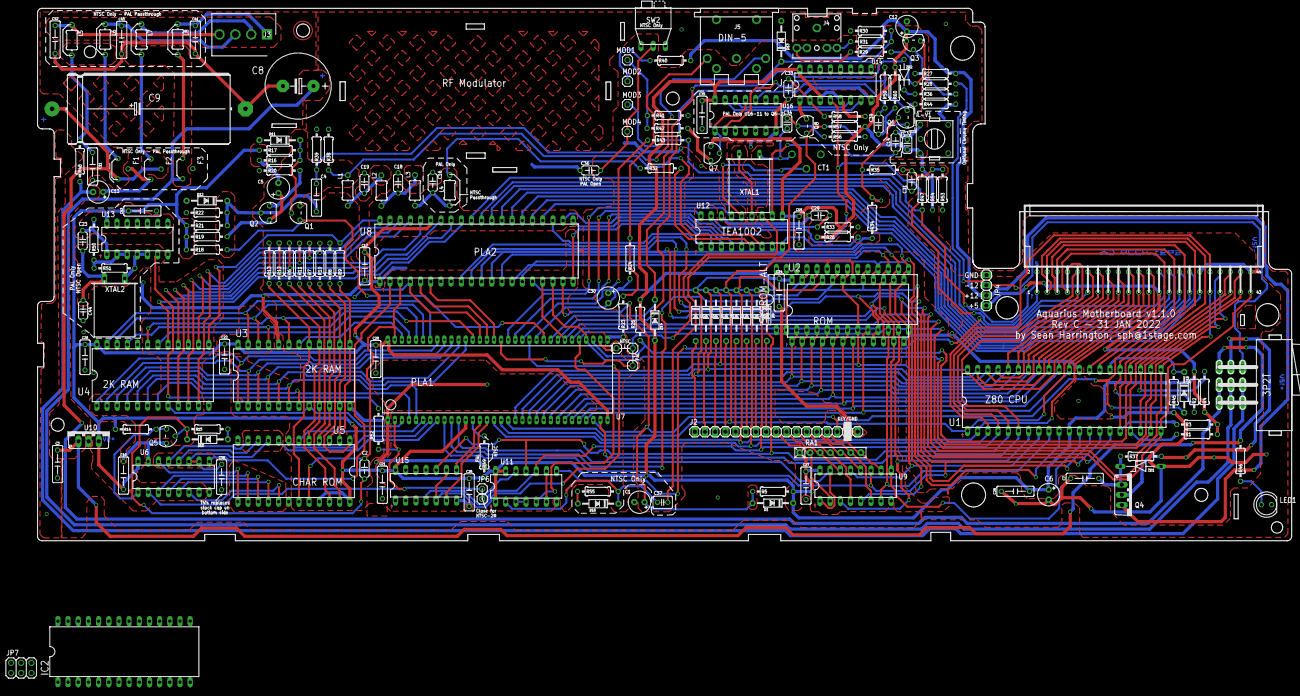
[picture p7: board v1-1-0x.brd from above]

Board: 2 copper layers, 313.0 x 132.9 mm, 183 parts (1 on the bottom side), 202 nets.

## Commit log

2020-08-10 First publish
    First publish of the Aquarius Motherboard v1-1-0 rev B
    [v1-1-0b.brd, v1-1-0b.sch]
2020-08-18 Edits/corrections from peer feedback.
    Corrected schematic reference to 526 (should be 625) in PLA.
    Put ALL chip signal labels ABOVE signal lines for consistency.
2020-08-18 Schematic and Board updates
    [v1-1-0b.sch]
2020-08-19 8/19/2020 updates
    [v1-1-0b.brd]
2020-08-19 Remove Gerber job files
2020-08-19 Edits for component values
    [v1-1-0b.brd, v1-1-0b.sch]
2020-08-20 Rev C created
    Thermal trace increases
    Value label clarifications/corrections
    Spacing corrections
    [v1-1-0c.brd, v1-1-0c.sch]
2020-08-30 Updated NTSC-only areas on BOARD and SCHEMATIC
2020-08-30 Clean up of values from MW input
    [v1-1-0c.brd, v1-1-0c.sch]
2020-09-09 Fix gitignore
    [v1-1-0c.brd, v1-1-0c.sch]
2020-10-19 Errata updates to BRD and SCH and PDFs
    [v1-1-0c.brd, v1-1-0c.sch]
2020-10-19 19 OCT 2020 fixes from Errata
    [v1-1-0c.brd, v1-1-0c.sch]
2020-10-21 Clean up
    [v1-1-0b.brd, v1-1-0b.sch, v1-1-0c.brd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]
2020-10-21 Directed errata to REV-B errata
    Since we're still troubleshooting RevB boards, deliniated errata to more correctly indicate that IT'S the board we're reviewing, even though it's the previous version from what's prominent in the folders.
2020-10-21 Fixed problem with floating pin 15 on U6
    [v1-1-0c.brd, v1-1-0c.sch]
2020-11-06 XTAL Boost cap added
    [v1-1-0c.brd, v1-1-0c.sch]
2020-12-09 09 DEC Update
    [v1-1-0c BOM.xlsx, v1-1-0c.brd, v1-1-0c.sch]
2020-12-09 Update v1-1-0c BOM.xlsx
    [v1-1-0c BOM.xlsx]
2021-01-15 January fixes
    [v1-1-0c BOM.xlsx, v1-1-0c.brd, v1-1-0c.dxf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]
2021-01-19 Rev C Full Release
    [v1-1-0b.brd, v1-1-0c BOM.xlsx, v1-1-0c.brd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]
2021-01-19 Clean-up, post go live
    [v1-1-0b.brd, v1-1-0b.sch]
2021-02-02 Tweaks to BRD and Gerber files for thermals
    [v1-1-0c.brd]
2021-03-17 Layout update
    Fix a positioning problem with right cartridge port alignment/screw hole.
    [v1-1-0c.brd, v1-1-0c.sch]
2021-04-20 Correct input voltages on PSU for schematic
    [v1-1-0c.brd, v1-1-0c.sch]
2022-03-13 Fix R20 values
    [v1-1-0c BOM.xlsx, v1-1-0d.brd, v1-1-0d.sch]
2022-04-29 Rev D updates
    [v1-1-0d BOM.xlsx, v1-1-0x.brd, v1-1-0x.sch]

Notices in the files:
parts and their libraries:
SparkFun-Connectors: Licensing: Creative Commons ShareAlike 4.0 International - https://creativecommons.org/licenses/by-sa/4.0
